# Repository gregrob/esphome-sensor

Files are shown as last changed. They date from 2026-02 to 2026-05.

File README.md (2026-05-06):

# ESPHome Sensor

An ESP32-S3 based sensor board system for ESPHome and Home Assistant, designed for outdoor environmental monitoring with a focus on hot water system and water tank level monitoring. Includes a complete mechanical system with 3D printable parts and a purpose-built outdoor 12V DC power distribution unit.

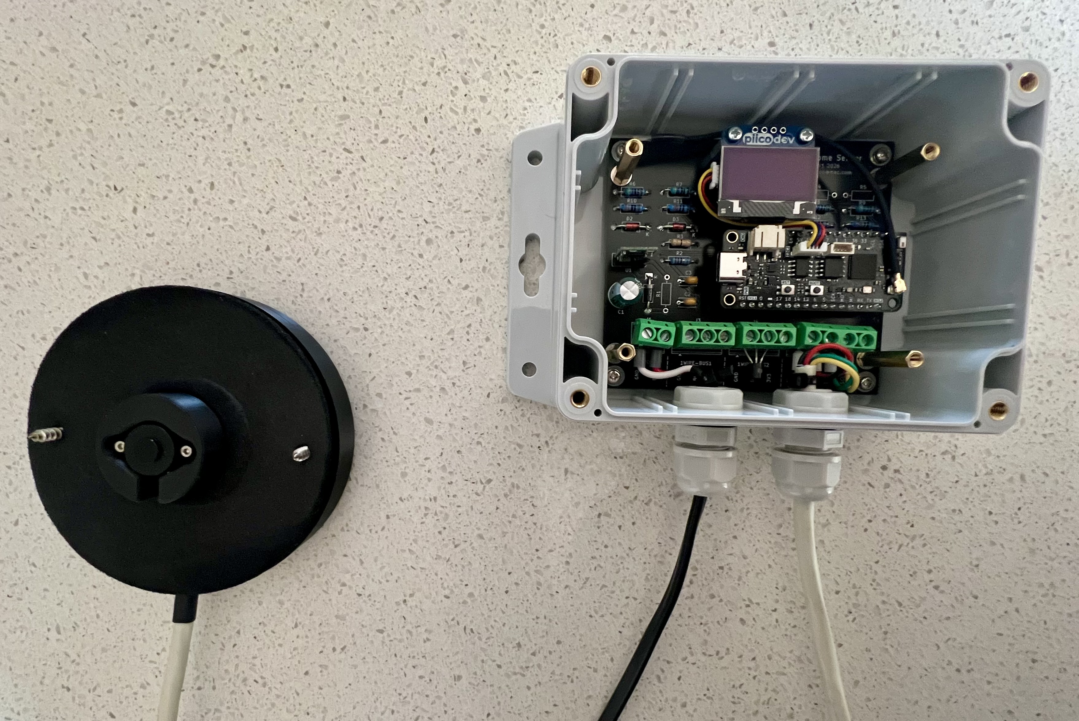
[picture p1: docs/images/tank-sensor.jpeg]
Tank Sensor with Adapter


*Tank Sensor with Adapter*

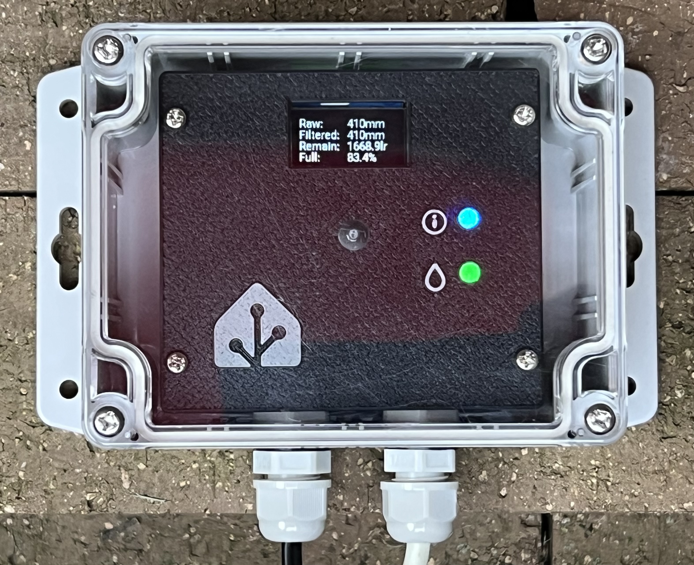
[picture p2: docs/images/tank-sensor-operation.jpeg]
Tank Sensor with Adapter


*Tank Sensor in Operation*

## Features

- ESP32-S3 (FeatherS3D) with WiFi and ESPHome integration
- PiicoDev OLED display for local status indication
- Dual 1-Wire buses for DS18B20 temperature sensors
- I2C expansion for ToF distance sensors (DFRobot SEN0590)
- RGB LED status indicator with gradient colour coding
- Outdoor-rated polycarbonate enclosures with cable glands
- Purpose-built 12V DC zone power distribution unit (PSU backboard)
- 3D printed PETG-HF mechanical components

## Main Hardware Overview

| Component | Description |
|---|---|
| ESP32-S3 FeatherS3D | Main microcontroller |
| PiicoDev OLED 128x64 | Local display |
| Pololu D24V5F5 | 5V step-down regulator |
| DFRobot SEN0590 | ToF distance sensor |
| DS18B20 | 1-Wire temperature sensors |
| Mean Well IRM-30-12ST | 12V 2.5A AC/DC PSU |

## Documentation

- [Hardware](docs/hardware.md) — PCB design, schematic, BOM, KiCad files
- [Mechanical](docs/mechanical.md) — 3D printing, enclosures, print settings, materials
- [PSU Backboard](docs/esphome-sensor-psu-backboard.md) — Outdoor 12V DC power distribution unit

## Project Structure

```
├── README.md
├── hardware/
│   └── kicad/              # KiCad schematic, PCB, Gerber, BOM
├── mechanical/
│   ├── fusion360/          # Fusion 360 source files (.f3d)
│   ├── exports/            # STL and STEP files for printing
│   └── icons/              # Incons used in the covers
├── datasheets/             # Component datasheets
└── docs/                   # Detailed documentation
    └── images/             # Build photos
```

## Applications

- Heat pump hot water system monitoring (temperature, capacity estimation)
- Rainwater tank level monitoring (ToF distance sensor)
- Outdoor distributed IoT sensor power distribution

## TODO

- [ ] Write `docs/hardware.md`
- [ ] Write `docs/mechanical.md`
- [ ] Better tank sensor demo photo
- [ ] Sync software for ESPHome in personal HA repo here
- [ ] UV rated cables for ToF sensor
- [ ] Finalise tank adaptr
  - [ ] Proper cable mounts
  - [ ] Brass inserts
  - [ ] Exit hole size increase
- [ ] Inprove 3D printed covers in PETG-HF
  - [ ] Document the improvement - 8 top layers, Hilbery Curve top surface, Gyroid infill, top surface speed 35 mm/s
- [ ] Move algorithm to device for the hws sensor
- [ ] Possibly 3D print UV shroud for devices
- [ ] Light pipes on the tank sensor

## License

MIT License — Copyright (c) 2026 Greg Robinson

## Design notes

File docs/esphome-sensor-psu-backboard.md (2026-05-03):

# ESPHome Sensor PSU Backboard

## Overview
The PSU backboard is a 3D printed mounting and protection component for the power supply unit of the ESPHome sensor boards. It provides structural support, cable management, and safety isolation for the power electronics. The board houses a 12V DC supply fed from 240V AC, with three independently fused DC outputs feeding external ESP32 sensor modules.

## Design Decisions

### Structural Design
- **Material**: PETG-HF — chosen for outdoor use, mechanical strength, and compatibility with heat inserts
- **Thickness**: 4.5mm to fully retain 4mm long heat inserts with 0.5mm clearance below
- **Wall Loops**: 4 for mechanical strength around heat insert bosses
- **Cable Management**: Integrated cable tie anchor points and cable routing channels on top surface
- **Fixings**: M3 brass heat inserts, 3.9mm hole diameter, 4.5mm deep, 0.3mm entry chamfer
- **Fillets**: 2mm on main board edges, 1mm on all other features

### Layout
- PSU mounted left-to-right, AC terminals facing left wall (short AC run)
- All cable glands on bottom wall — AC left, DC right (water ingress protection)
- 6-way terminal block centre-right: 3x GND direct out, 3x DC+ through inline fuses
- Fuse holders between terminal block and DC cable glands
- AC and DC sides physically separated across the plate

### Safety Considerations
- **AC Isolation**: Printed cover over PSU AC terminals to prevent accidental contact
- **Fusing**: 250mA fast-blow fuse on each DC output circuit (one per ESP32 module)
- **Ventilation**: Not required — low dissipation at 250mA fused output
- **Fuse Access**: Accessible inline fuse holder mounting for easy maintenance

## Print Settings

### Material
- Bambu Labs PETG-HF
- Print temperature: 235-240°C nozzle, 70-75°C bed (240°C initial layer, 235°C other layers)
- Calibrated flow rate defaults on Bambu Labs P2S

### Print Orientation
- **Recommended Orientation**: Backboard flat on bed, cable clips and bosses printing upward
- **Support Material**: None
- **Build Plate Adhesion**: None required — ensure bed is clean (IPA wipe) before printing

### Quality Settings
- **Walls**: 4
- **Top/Bottom Layers**: 5
- **Ironing**: Top surfaces only
- **Ironing Speed**: 15mm/s
- **Ironing Flow**: 20%
- **Ironing Line Spacing**: 0.08mm
- **Ironing Pattern**: Rectilinear

## Heat Insert Installation

- **Insert spec**: M3 x L4 x OD4.2mm (top) / OD3.75mm (bottom)
- **Hole size**: 3.9mm diameter, 4.5mm deep
- **Entry chamfer**: 0.3mm (edge break only — do not chamfer deeply or insert will tilt)
- **Technique**: Let insert sit level in hole before applying iron. Soldering iron weight provides gentle downward pressure, allow heat to do the work over 5-10 seconds. Let cool fully before applying load.
- **Note**: 3.85mm hole confirmed too tight. 3.9mm confirmed correct for this insert with unironed surfaces. Ironed surfaces may require 4.0mm or post-print clearing with 4mm drill bit.

## Assembly Notes

### Required Hardware
| Item | Source |
|---|---|
| Bambu Lab PETG-HF (Black) | [Bambu Lab](https://au.store.bambulab.com/products/petg-hf) |
| M3 Threaded Inserts M3xL4xOD4.2 | [Amazon AU](https://www.amazon.com.au/dp/B0BBSLL6G7) |
| Meanwell IRM-30-12ST 30W 12V 2.5A PSU | [Jaycar MP3302](https://www.jaycar.com.au/30w-12v-2-5a-mini-power-supply/p/MP3302) |
| 250VAC 10A M205 Inline Fuse Holder | [Jaycar SZ2030](https://www.jaycar.com.au/250vac-10a-m205-panel-mount-fuse-holder/p/SZ2030) |
| 250mA M205 Fast-Blow Fuse 250VAC | [Jaycar SF2154](https://www.jaycar.com.au/250ma-m205-quick-blow-fuse-250vac/p/SF2154) |
| 6 Amp 12-way Screw Terminal Strip (6 positions used) | [Jaycar HM3194](https://www.jaycar.com.au/6-amp-12-way-screw-terminal-strip/p/HM3194) |
| Polycarbonate Enclosure 171 x 121 x 80mm | [Jaycar HB6221](https://www.jaycar.com.au/polycarbonate-enclosure-with-flange-171-x-121-x-80mm/p/HB6221) |
| 3-6.5mm DIA Waterproof Cable Glands | [Jaycar HP0720](https://www.jaycar.com.au/3-6-5mm-dia-waterproof-cable-glands-pack-of-2/p/HP0720) |
| 7.5A 2-core cable (12V input wiring) | [Jaycar WH3057](https://www.jaycar.com.au/7-5a-2-core-tinned-dc-power-cable-red-white/p/WH3057)|
| Ferrule crimps (matched to wire gauge) | [Amazon AU](https://www.amazon.com.au/dp/B0BZPPLP5W)|

### Wiring Notes
- All cable glands on bottom wall for water ingress protection
- DC outputs: 250mA fast-blow fuse per output circuit (3 total)
- Terminal block positions: +in(F1) | +in(F2) | +in(F3) | +out(F1) | +out(F2) | +out(F3) | GND | GND | GND
- Ferrule crimps on all wire ends
- 12V input wired with 7.5A 2-core cable (oversized — lowest available gauge)

### Assembly Sequence
1. Install heat inserts at 250-260°C (250°C worked for me)
2. Mount PSU to backboard with M3 screws through AC terminal cover/bracket
3. Mount terminal block and fuse holders
4. Wire AC side: cable gland → inline fuse → PSU L and N terminals
5. Wire DC side: PSU +/− → terminal block → fuses → DC cable glands
6. Install backboard into enclosure
7. Install cable glands and route cables

## Images

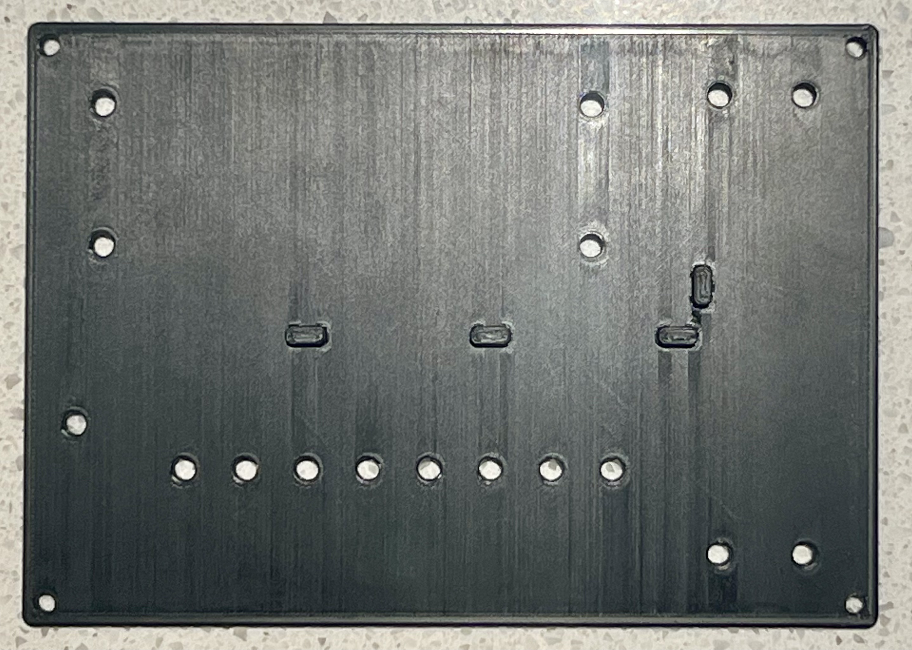
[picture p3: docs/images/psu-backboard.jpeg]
PSU Backboard


*3D printed PSU backboard showing heat insert bosses and cable management features*

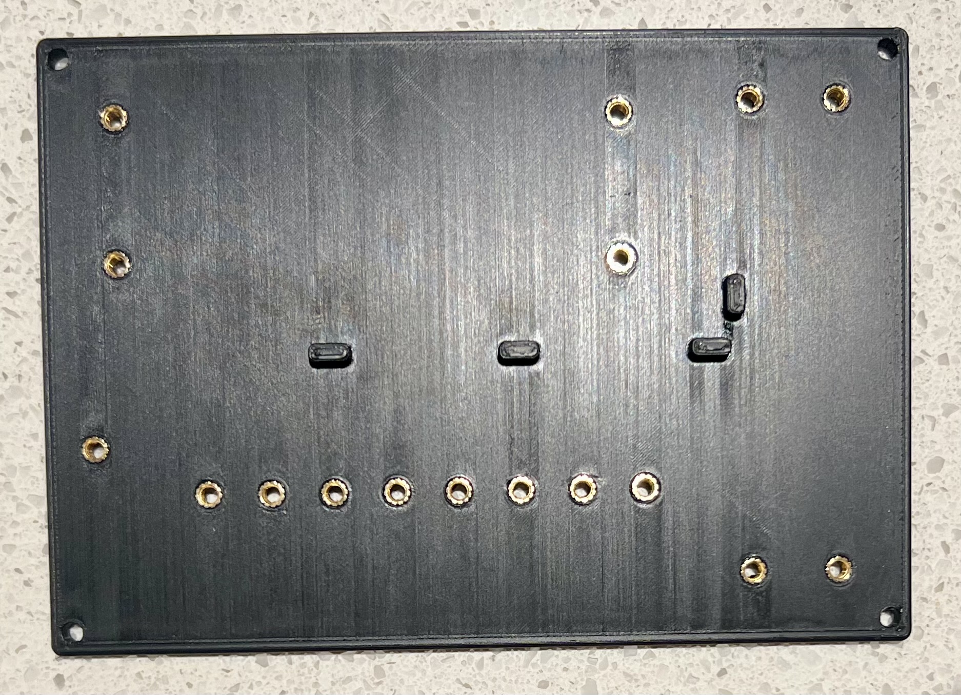
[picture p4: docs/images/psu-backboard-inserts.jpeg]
PSU Backboard with Brass Inserts


*Heat inserts installed*

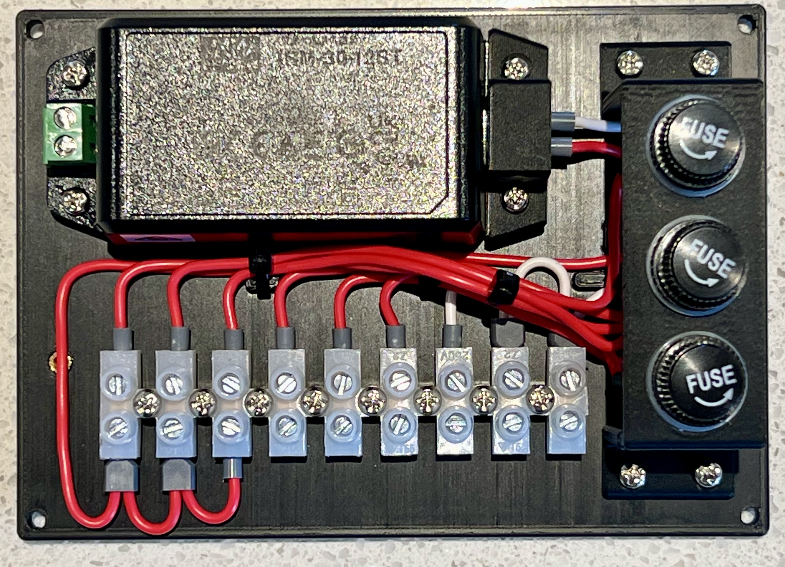
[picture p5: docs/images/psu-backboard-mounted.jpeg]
PSU Backboard Mounted


*Backboard mounted in enclosure with PSU, terminal block, and fuse holders*

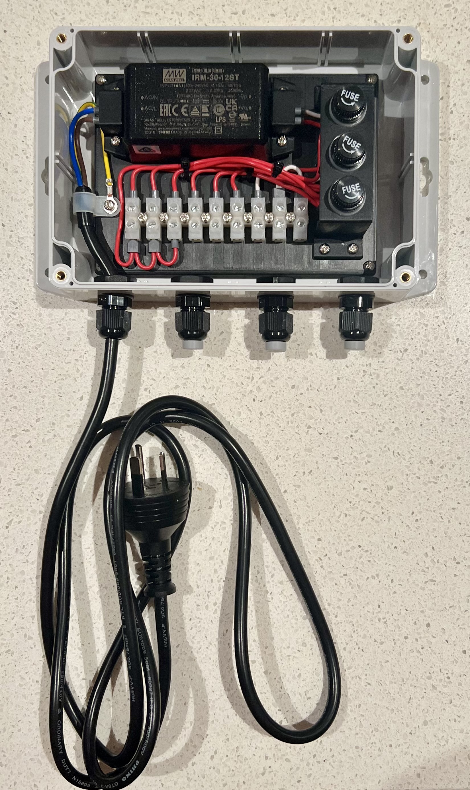
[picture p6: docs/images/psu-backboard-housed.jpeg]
PSU Backboard Housed


*Complete assembly ready for deployment*

## Version History
| Version | Notes |
|---|---|
| v1 | Initial test print — ironing settings tuned, insert hole confirmed |

## Design Files
- **Source**: `mechanical\fusion360\esphome-sensor-psu-backboard.f3d` (Fusion 360)
- **Backboard Export**: `mechanical\exports\esphome-sensor-psu-backboard[-vx].stl`
- **PSU Terminal Cover/Bracket**: `mechanical\exports\esphome-sensor-psu-terminal-cover[-vx].stl`
- **Fuse Holder Mount**: `mechanical\exports\esphome-sensor-psu-fuse-holder[-vx].stl`

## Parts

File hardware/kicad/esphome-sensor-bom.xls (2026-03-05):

Reference | Qty | Value | Have | Need |  | DNP | Exclude from BOM | Exclude from Board | Footprint | Datasheet
C1 | 1 | 100uF 35V | 1 | 1 | https://www.jaycar.com.au/100uf-35vdc-low-esr-electrolytic-capacitor/p/RE6334 |  |  |  | Capacitor_THT:CP_Radial_D8.0mm_P3.50mm | ~
C2,C3 | 2 | 100nF 50V | 2 | 2 | https://www.jaycar.com.au/100nf-50vdc-monolithic-capacitor/p/RC5490 |  |  |  | Capacitor_THT:C_Disc_D5.0mm_W2.5mm_P5.00mm | ~
D1 | 1 | 1N4007 | 0 | 1 | https://www.jaycar.com.au/1n4007-1a-1000v-diode-pack-of-4/p/ZR1007 |  |  |  | Diode_THT:D_DO-41_SOD81_P10.16mm_Horizontal | http://www.vishay.com/docs/88503/1n4001.pdf
D2,D3 | 2 | 1N4729A* | 0 | 4 | https://www.jaycar.com.au/3-6v-1n4729-1-watt-zener-diode/p/ZR1399 |  |  |  | Diode_THT:D_DO-41_SOD81_P10.16mm_Horizontal | https://www.vishay.com/docs/85816/1n4728a.pdf
J1 | 1 | DC POWER IN | 0 | 2 | https://core-electronics.com.au/2-pin-screw-terminal-block-5mm-pitch.html |  |  |  | TerminalBlock_Phoenix:TerminalBlock_Phoenix_PT-1,5-2-5.0-H_1x02_P5.00mm_Horizontal | ~
J2 | 1 | OLED | 0 | 2 | https://core-electronics.com.au/piicodev-oled-display-module-128x64-ssd1306.html |  |  |  | PiicoDev_OLED_Module:PiicoDev_OLED_Module | ~
J3 | 1 | 1WIRE-BUS1 | 0 | 2 | https://core-electronics.com.au/50mm-screw-terminal-block-3p.html |  |  |  | TerminalBlock_Phoenix:TerminalBlock_Phoenix_PT-1,5-3-5.0-H_1x03_P5.00mm_Horizontal | ~
J4 | 1 | 1WIRE-BUS2 | 0 | 2 | https://core-electronics.com.au/50mm-screw-terminal-block-3p.html |  |  |  | TerminalBlock_Phoenix:TerminalBlock_Phoenix_PT-1,5-3-5.0-H_1x03_P5.00mm_Horizontal | ~
J5 | 1 | I2C | 0 | 4 | https://core-electronics.com.au/2-pin-screw-terminal-block-5mm-pitch.html |  |  |  | TerminalBlock_Phoenix:TerminalBlock_Phoenix_PT-1,5-4-5.0-H_1x04_P5.00mm_Horizontal | ~
R1 | 1 | 0R* | 0 | 0 |  |  |  |  | Resistor_THT:R_Axial_DIN0207_L6.3mm_D2.5mm_P10.16mm_Horizontal | ~
R2 | 1 | 22R | 7 | 0 | https://www.jaycar.com.au/22-ohm-0-5-watt-metal-film-resistors-pack-of-8/p/RR0532 |  |  |  | Resistor_THT:R_Axial_DIN0207_L6.3mm_D2.5mm_P10.16mm_Horizontal | ~
R3 | 1 | 0R | 5 | 0 | https://www.jaycar.com.au/0-ohm-0-25-watt-carbon-film-resistors-pack-of-8/p/RR1500 |  |  |  | Resistor_THT:R_Axial_DIN0207_L6.3mm_D2.5mm_P10.16mm_Horizontal | ~
R4,R5 | 2 | 4.7K* | 4 | 0 | https://www.jaycar.com.au/4-7k-ohm-0-5-watt-metal-film-resistors-pack-of-8/p/RR0588 |  |  |  | Resistor_THT:R_Axial_DIN0207_L6.3mm_D2.5mm_P10.16mm_Horizontal | ~
R6,R7,R8,R9 | 4 | 4.7K | 0 | 8 | https://www.jaycar.com.au/4-7k-ohm-0-5-watt-metal-film-resistors-pack-of-8/p/RR0588 | https://core-electronics.com.au/600-pack-of-1-4-watt-1-resistors-30-values-20-of-each.html |  |  | Resistor_THT:R_Axial_DIN0207_L6.3mm_D2.5mm_P10.16mm_Horizontal | ~
R10,R11,R12,R13 | 4 | 330R | 7 | 0 | https://www.jaycar.com.au/330-ohm-0-5-watt-metal-film-resistors-pack-of-8/p/RR0560 |  |  |  | Resistor_THT:R_Axial_DIN0207_L6.3mm_D2.5mm_P10.16mm_Horizontal | ~
U1 | 1 | D24V5F5 | 1 | 1 | https://core-electronics.com.au/pololu-5v-500ma-step-down-voltage-regulator-d24v5f5.html |  |  |  | D24V5F5:D24V5F5
U2 | 1 | FeatherS3D | 2 | 0 | https://unexpectedmaker.com/shop.html#!/FeatherS3-D/p/759221736 |  |  |  | FeatherS3D:FeatherS3D
10 sets M3 * 20 hexagonal standoffs mounting kit |  |  | 0 | 1 | https://core-electronics.com.au/10-sets-m3-20-hexagonal-standoffs-mounting-kit.html
Aluminum Standoff for Raspberry Pi: 11mm Length, 4mm M2.5 Thread, M-F (4-Pack) |  |  | 0 | 1 | https://core-electronics.com.au/aluminum-standoff-for-raspberry-pi-11mm-length-4mm-m2-5-thread-m-f-4-pack.html
Aluminum Standoff for Raspberry Pi: 18.6mm Length, 6mm M2.5 Thread, M-F (4-Pack) |  |  | 0 | 1 | https://core-electronics.com.au/aluminum-standoff-for-raspberry-pi-18-6mm-length-6mm-m2-5-thread-m-f-4-pack.html
Machine Screw: M2.5, 6mm Length, Phillips (25-pack) |  |  | 0 | 1 | https://core-electronics.com.au/machine-screw-m2-5-6mm-length-phillips-25-pack.html
Machine Hex Nut: M2.5 (25-pack) |  |  | 0 | 1 | https://core-electronics.com.au/machine-hex-nut-m2-5-25-pack.html
OLED Cable - 50mm |  |  | 0 | 2 | https://core-electronics.com.au/piicodev-cable-50mm.html
OLED Cable - 100mm |  |  | 0 | 2 | https://core-electronics.com.au/piicodev-cable-100mm.html
 |  |  |  | ordered core electronics
Consider |  |  |  | ordered from jaycar
PiicoDev Air Quality Sensor ENS160 (https://core-electronics.com.au/piicodev-air-quality-sensor-ens160.html)
PiicoDev RFID Module (NFC 13.56MHz) (https://core-electronics.com.au/piicodev-rfid-module.html)

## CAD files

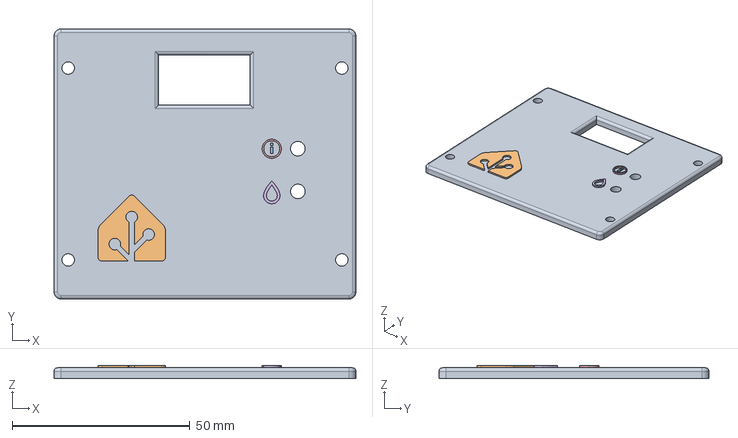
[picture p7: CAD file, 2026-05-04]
mechanical/exports/esphome-sensor-pcb-cover-tank-v1.step
85.0 x 76.0 x 3.60 mm

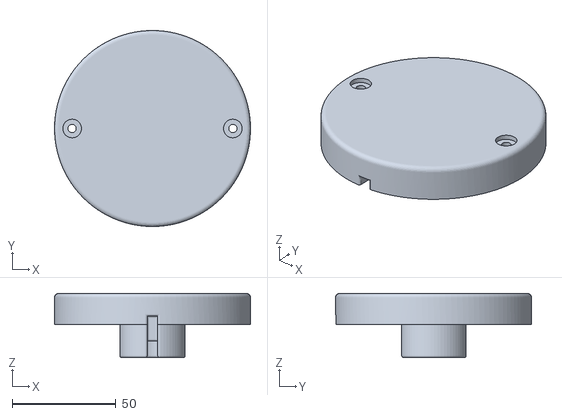
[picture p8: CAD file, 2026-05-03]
mechanical/exports/esphome-sensor-tank-adapter-v1.stl
94.5 x 94.5 x 31.0

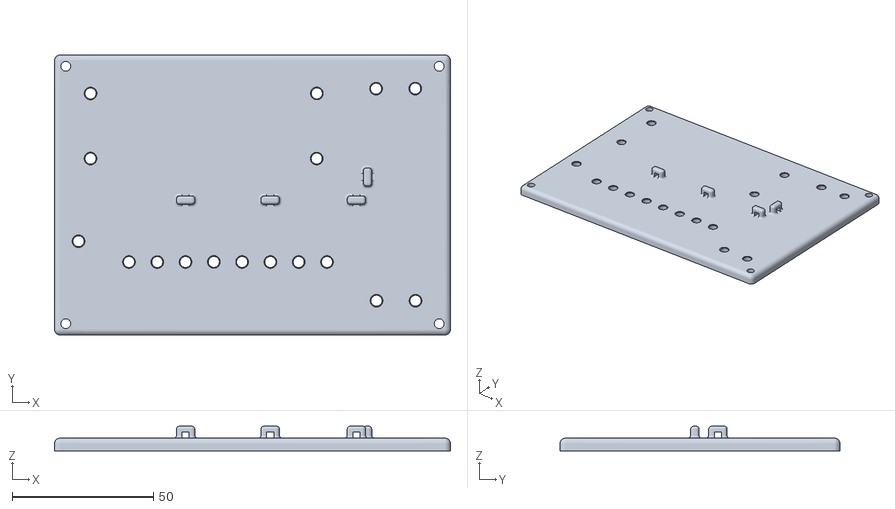
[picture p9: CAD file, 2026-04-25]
mechanical/exports/esphome-sensor-psu-backboard-v2.stl
140.0 x 99.0 x 8.71

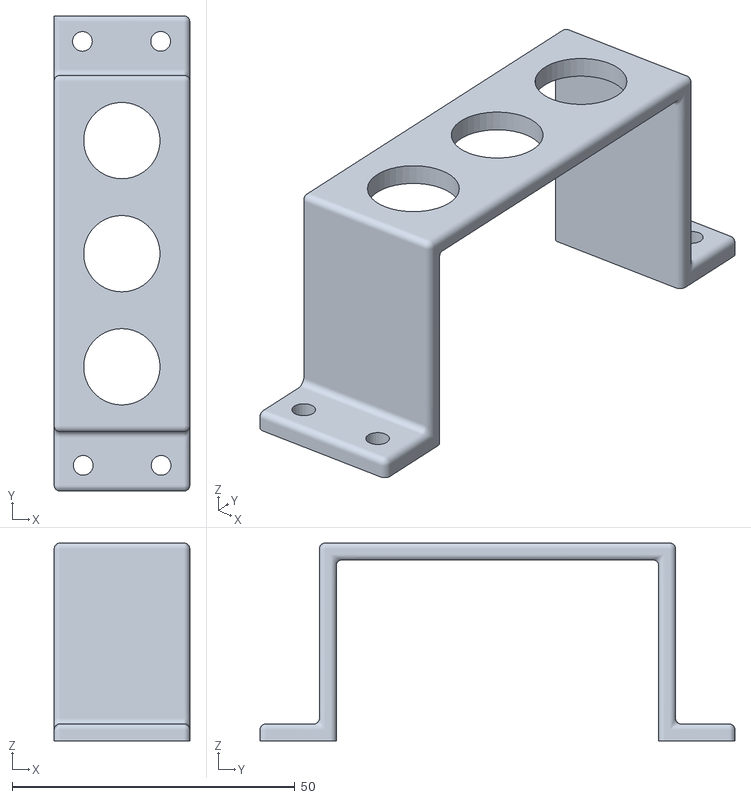
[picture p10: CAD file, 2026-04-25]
mechanical/exports/esphome-sensor-psu-fuse_holder-v1.stl
24.0 x 84.0 x 35.0

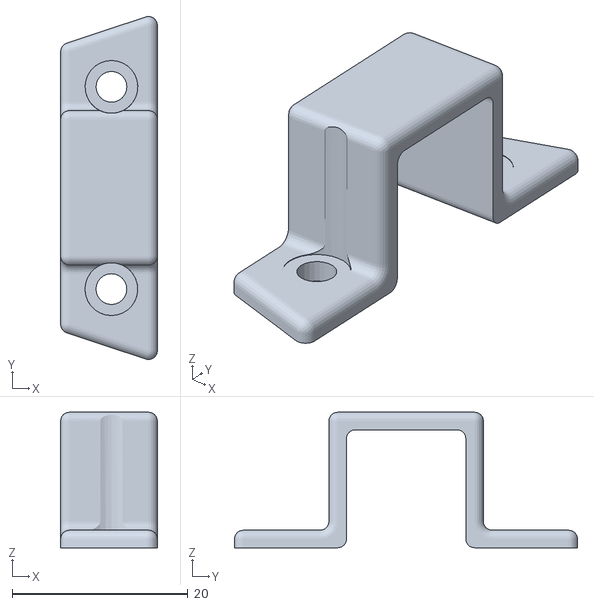
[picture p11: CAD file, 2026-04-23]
mechanical/exports/esphome-sensor-psu-terminal-cover-v2.stl
11.0 x 39.0 x 15.4

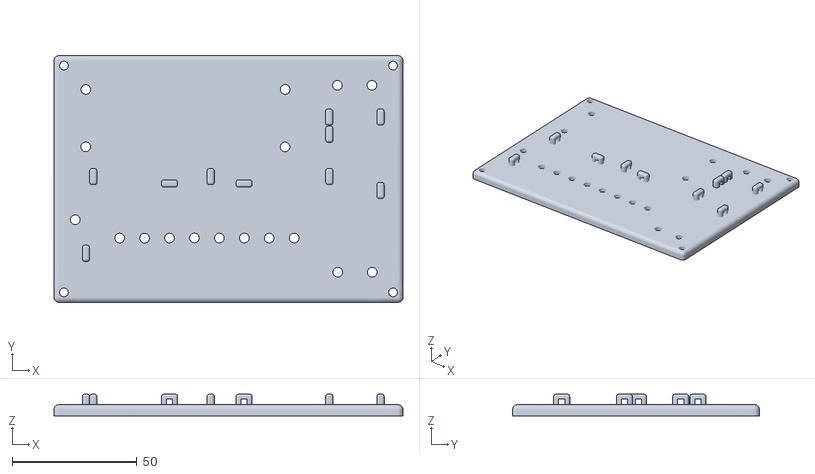
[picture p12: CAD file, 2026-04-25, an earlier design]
mechanical/exports/esphome-sensor-psu-backboard-v1.stl
140.0 x 99.0 x 8.71

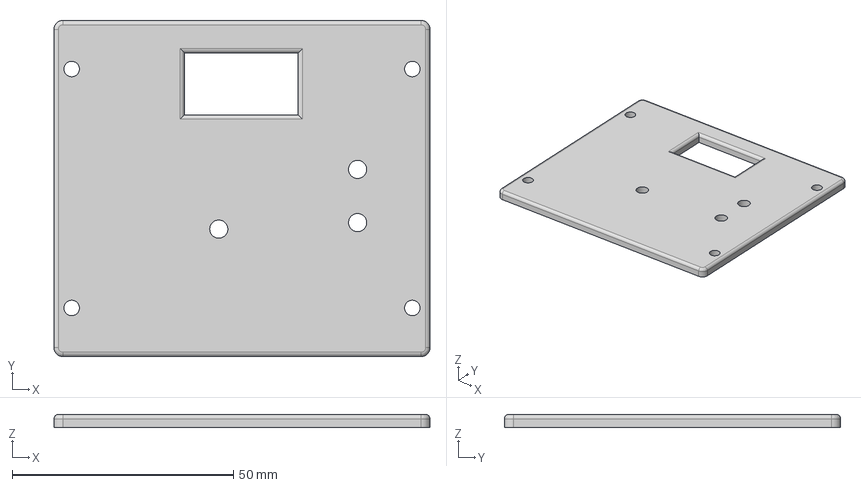
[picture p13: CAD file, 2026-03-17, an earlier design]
mechanical/exports/esphome-sensor-pcb-cover-hws-v2.step
85.0 x 76.0 x 3.00 mm

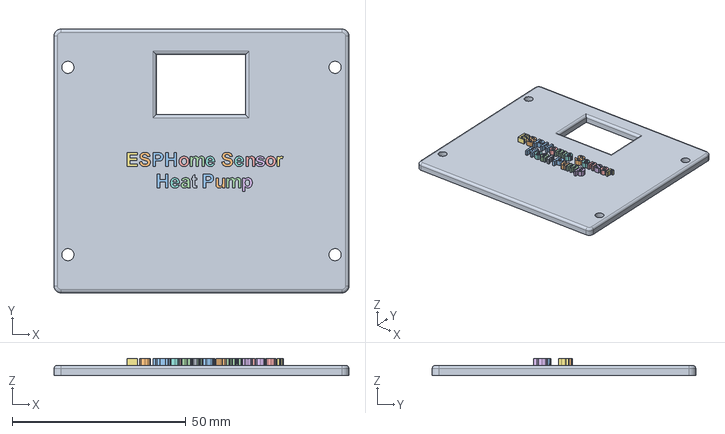
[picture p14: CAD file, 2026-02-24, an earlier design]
mechanical/exports/esphome-sensor-pcb-cover-hws-v1.step
85.0 x 76.0 x 5.00 mm

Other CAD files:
mechanical/exports/esphome-sensor-pcb-cover-hws-v3.step
mechanical/fusion360/esphome-sensor-pcb-cover.f3d
mechanical/fusion360/esphome-sensor-psu-backboard.f3d
mechanical/fusion360/esphome-sensor-tank-adapter.f3d

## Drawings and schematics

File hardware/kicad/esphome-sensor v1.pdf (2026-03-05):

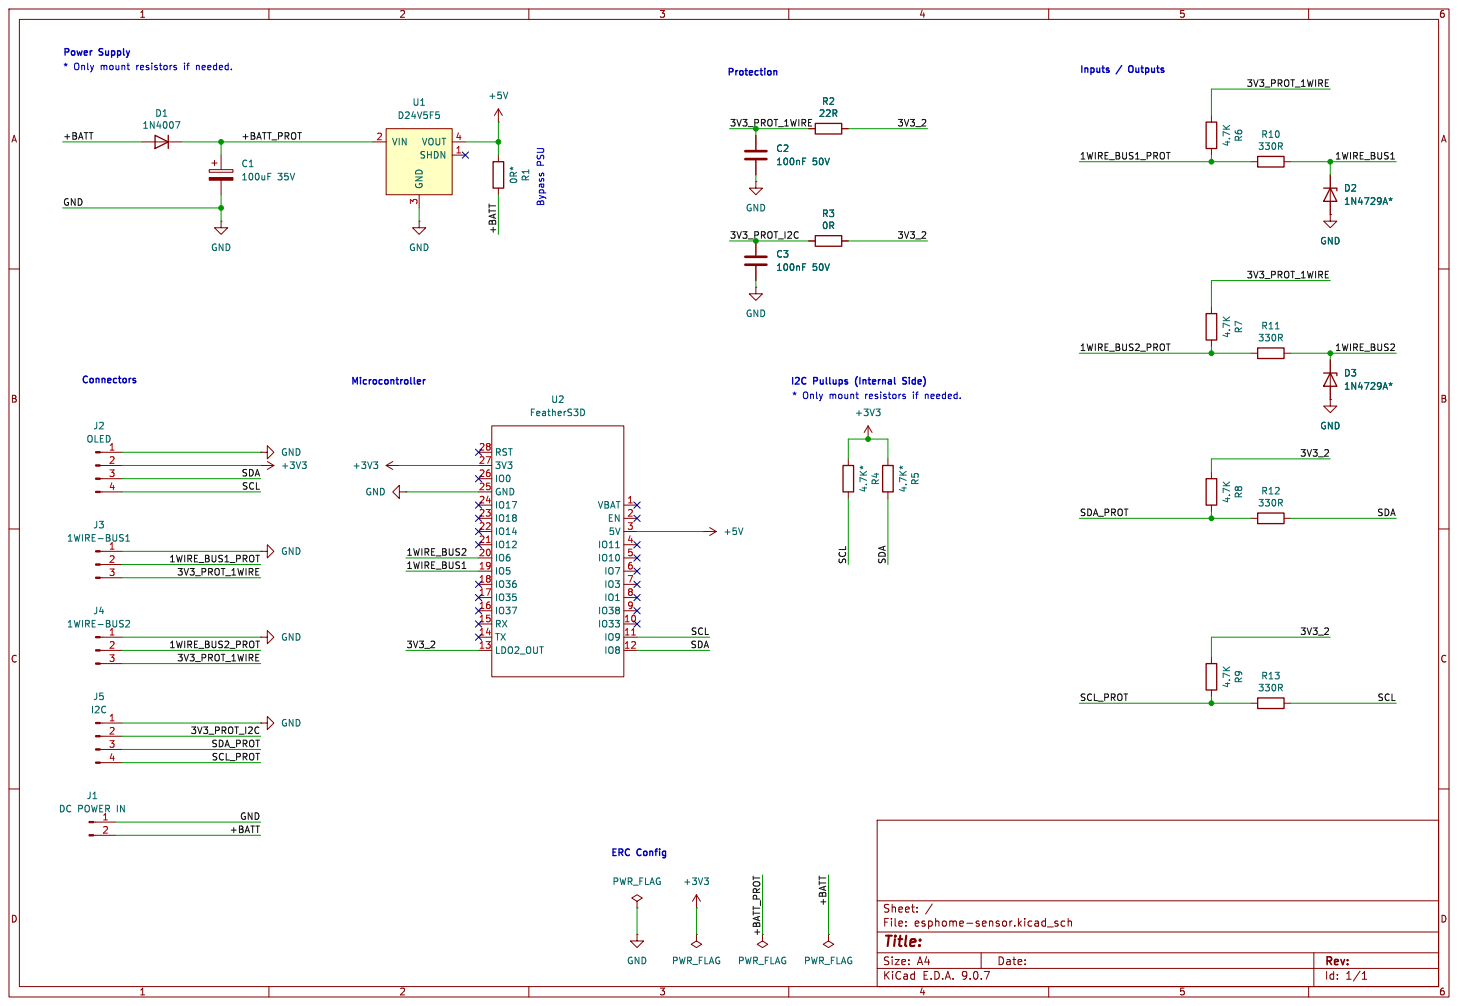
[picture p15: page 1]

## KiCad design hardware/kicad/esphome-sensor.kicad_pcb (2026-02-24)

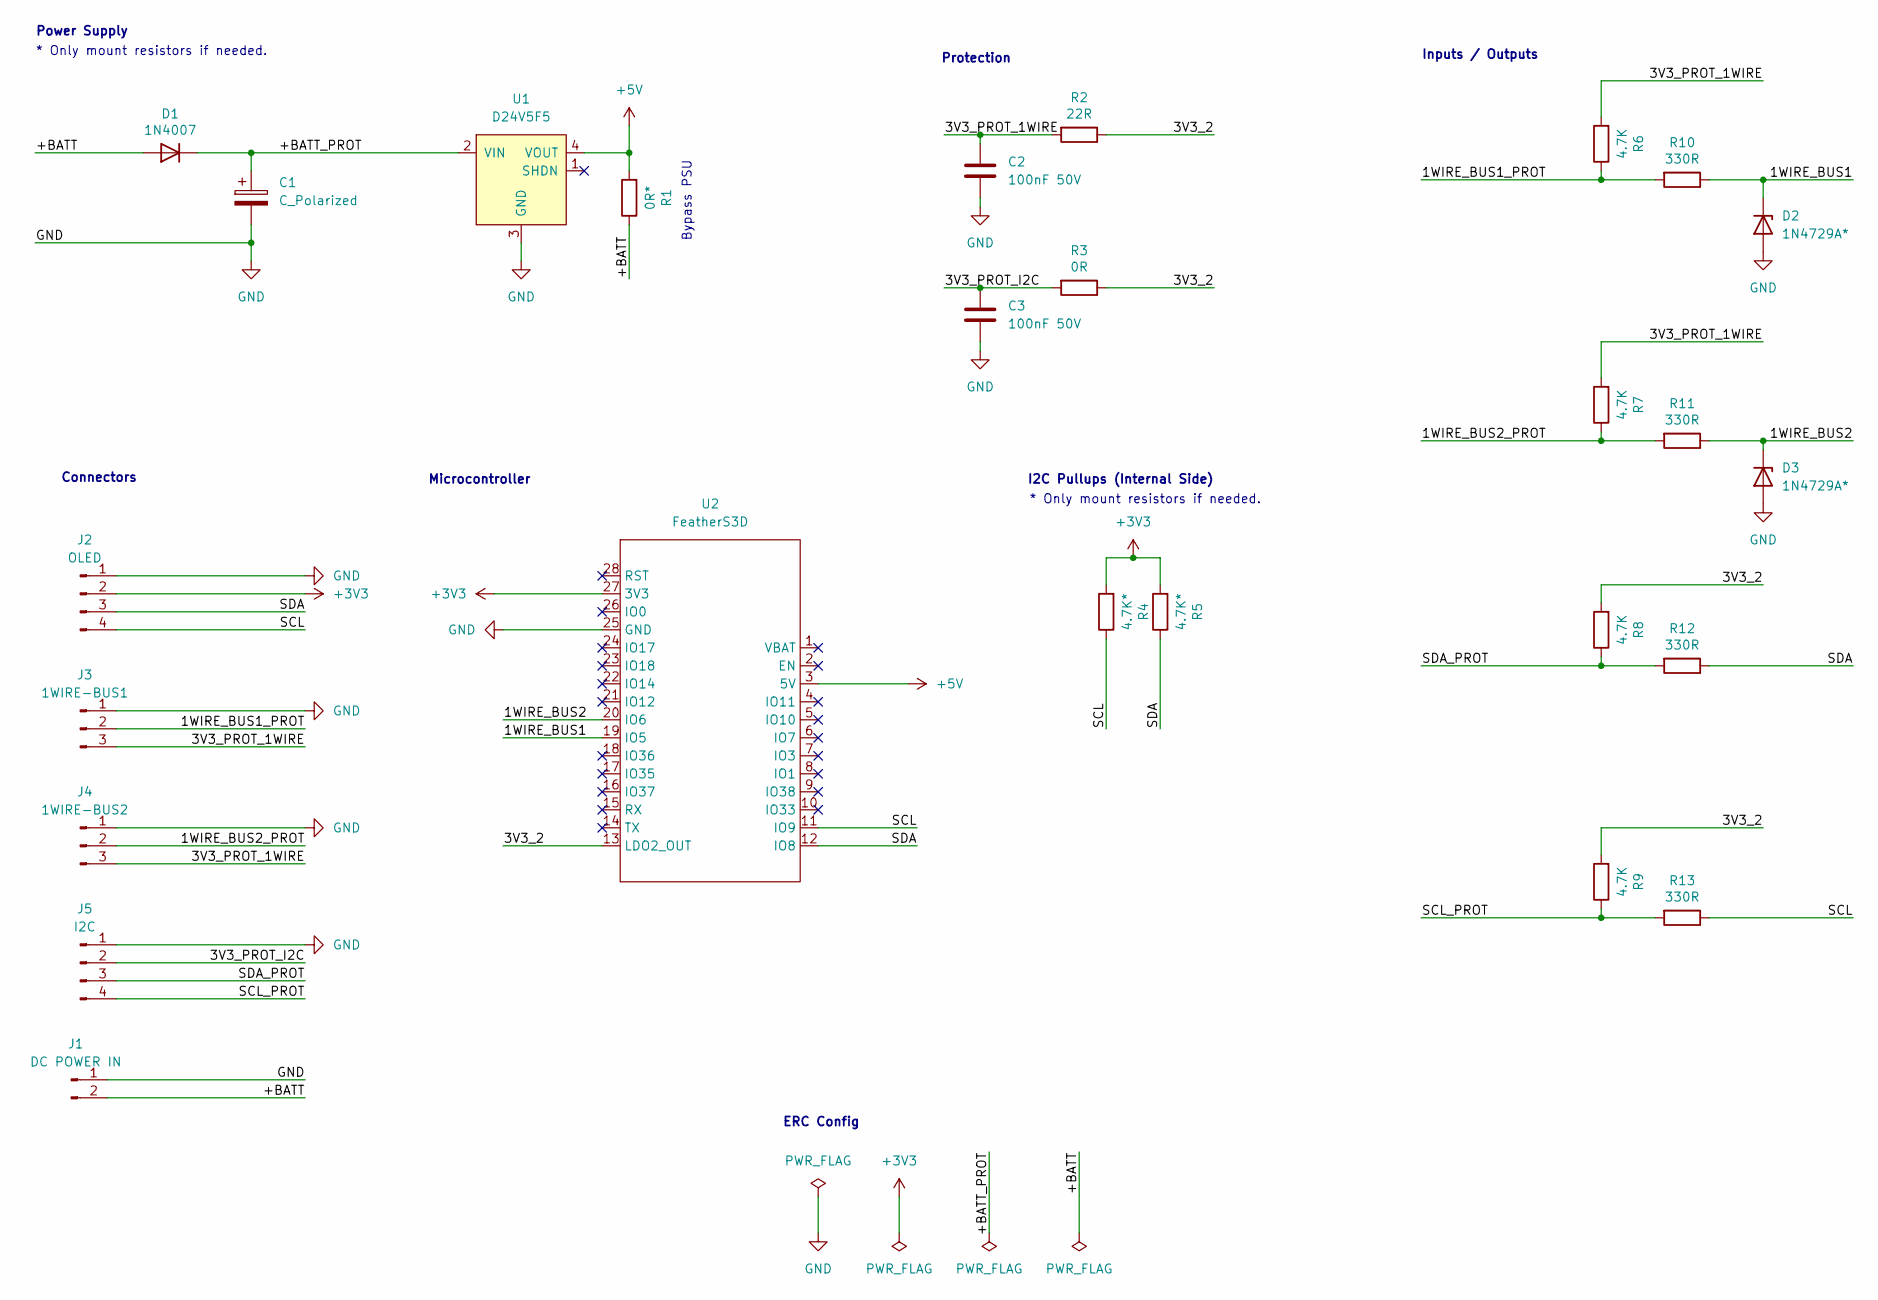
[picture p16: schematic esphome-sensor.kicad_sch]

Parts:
C1: C_Polarized; CP_Radial_D8.0mm_P3.50mm
C2, C3: 100nF 50V; C_Disc_D5.0mm_W2.5mm_P5.00mm
D1: 1N4007; D_DO-41_SOD81_P10.16mm_Horizontal
D2, D3: 1N4729A*; D_DO-41_SOD81_P10.16mm_Horizontal
J1: DC POWER IN; TerminalBlock_Phoenix_PT-1,5-2-5.0-H_1x02_P5.00mm_Horizontal
J2: OLED; PiicoDev_OLED_Module
J3: 1WIRE-BUS1; TerminalBlock_Phoenix_PT-1,5-3-5.0-H_1x03_P5.00mm_Horizontal
J4: 1WIRE-BUS2; TerminalBlock_Phoenix_PT-1,5-3-5.0-H_1x03_P5.00mm_Horizontal
J5: I2C; TerminalBlock_Phoenix_PT-1,5-4-5.0-H_1x04_P5.00mm_Horizontal
R1: 0R*; R_Axial_DIN0207_L6.3mm_D2.5mm_P10.16mm_Horizontal
R2: 22R; R_Axial_DIN0207_L6.3mm_D2.5mm_P10.16mm_Horizontal
R3: 0R; R_Axial_DIN0207_L6.3mm_D2.5mm_P10.16mm_Horizontal
R4, R5: 4.7K*; R_Axial_DIN0207_L6.3mm_D2.5mm_P10.16mm_Horizontal
R6, R7, R8, R9: 4.7K; R_Axial_DIN0207_L6.3mm_D2.5mm_P10.16mm_Horizontal
R10, R11, R12, R13: 330R; R_Axial_DIN0207_L6.3mm_D2.5mm_P10.16mm_Horizontal
U1: D24V5F5
U2: FeatherS3D

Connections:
+3V3: J2.2, R4.2, R5.2, U2.27 (3V3)
+5V: R1.2, U1.4 (VOUT), U2.3 (5V)
/1WIRE_BUS1: D2.1 (K), R10.1, U2.19 (IO5)
/1WIRE_BUS1_PROT: J3.2, R6.1, R10.2
/1WIRE_BUS2: D3.1 (K), R11.1, U2.20 (IO6)
/1WIRE_BUS2_PROT: J4.2, R7.1, R11.2
/3V3_2: R2.1, R3.1, R8.2, R9.2, U2.13 (LDO2_OUT)
/3V3_PROT_1WIRE: C2.1, J3.3, J4.3, R2.2, R6.2, R7.2
/3V3_PROT_I2C: C3.1, J5.2, R3.2
/+BATT: D1.2 (A), J1.2, R1.1
/+BATT_PROT: C1.1, D1.1 (K), U1.2 (VIN)
/SCL: J2.4, R4.1, R13.1, U2.11 (IO9)
/SCL_PROT: J5.4, R9.1, R13.2
/SDA: J2.3, R5.1, R12.1, U2.12 (IO8)
/SDA_PROT: J5.3, R8.1, R12.2
GND: C1.2, C2.2, C3.2, D2.2 (A), D3.2 (A), J1.1, J2.1, J3.1, J4.1, J5.1, U1.3 (GND), U2.25 (GND)

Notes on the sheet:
ERC Config
Connectors
I2C Pullups (Internal Side)
* Only mount resistors if needed.
Inputs / Outputs
Bypass PSU
Microcontroller
Protection
Power Supply

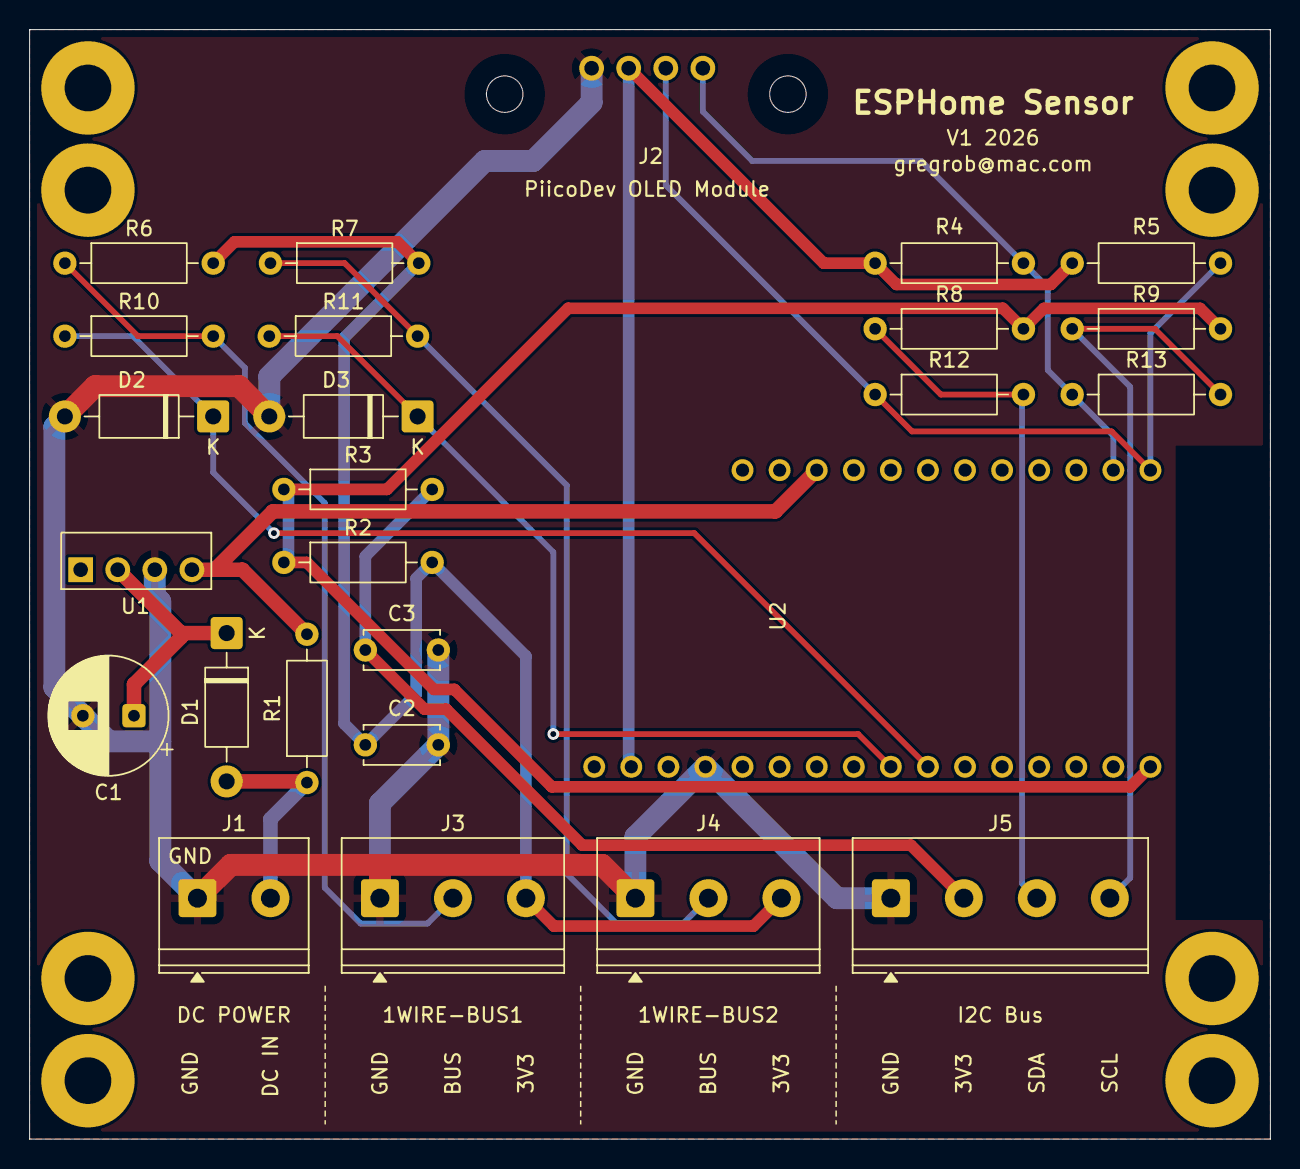
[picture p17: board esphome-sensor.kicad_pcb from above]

Board: 2 copper layers, 85.0 x 76.0 mm, 34 parts (0 on the bottom side), 16 nets.

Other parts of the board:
H1, H2, H3, H4, H5, H6, H7, H8: MountingHole_3.2mm_M3_Pad

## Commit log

2026-02-24 initial version of hardware
    [esphome-sensor-B_Cu.gbr, esphome-sensor-B_Mask.gbr, esphome-sensor-B_Paste.gbr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]
2026-02-24 step exports for pcb and cover
    [esphome-sensor-pcb-cover-v1.step]
2026-02-26 filter cap defined
    [esphome-sensor.kicad_sch]
2026-02-26 initial BOM
    [esphome-sensor.csv]
2026-03-05 schematic pdf and bom
    [esphome-sensor-bom.xls]
2026-03-17 final proposal for top cover with 2x LED's and icons
    [esphome-sensor-pcb-cover-v2.step, esphome-sensor-pcb-cover-v3.step]
2026-04-23 start of psu build
    [esphome-sensor-psu-backboard.f3d, esphome-sensor-psu-terminal-cover-v2.stl]
2026-04-25 add PSU backboard documentation with design, print settings, and assembly notes
2026-04-25 refine PSU backboard documentation with detailed design specifications, print settings, and assembly instructions
2026-04-25 add new STL files for PSU backboard and fuse holder, and update Fusion 360 model
    [esphome-sensor-psu-backboard-v1.stl, esphome-sensor-psu-backboard-v2.stl, esphome-sensor-psu-backboard.f3d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]
2026-04-25 add documentation for ESPHome Sensor PSU backboard including design, print settings, and assembly instructions
2026-05-03 add new STL and Fusion 360 files for ESPHome sensor tank adapter
    [esphome-sensor-tank-adapter-v1.stl, esphome-sensor-tank-adapter.f3d]
2026-05-03 add images and documentation for PSU backboard assembly and features
2026-05-04 refactored pcb cover
    [esphome-sensor-pcb-cover-hws-v1.step, esphome-sensor-pcb-cover-hws-v2.step, esphome-sensor-pcb-cover-hws-v3.step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]
2026-05-04 tank pcb cover added
    [esphome-sensor-pcb-cover-tank-v1.step]
2026-05-05 add tank sensor demo photo to README and update feature list
2026-05-05 parameters for best quality 3d printed covers with embossing
2026-05-06 add tank sensor operation image to README
